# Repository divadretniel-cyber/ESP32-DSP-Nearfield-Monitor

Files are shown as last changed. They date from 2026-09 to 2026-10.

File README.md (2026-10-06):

# Nearfield Monitor with ESP32-DSP-4x50W-Amplifier

A studio monitor with a DSP amplifier board, based on an esp32-S3.

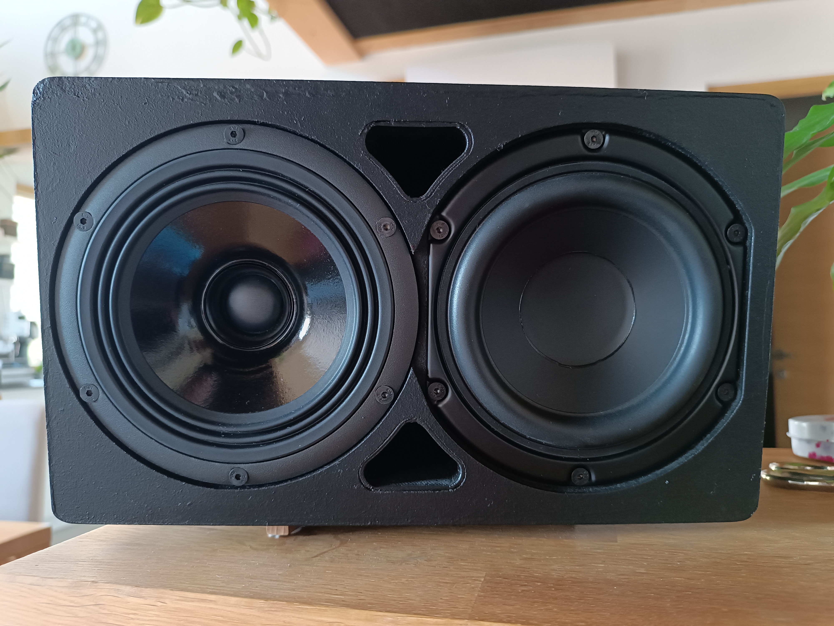
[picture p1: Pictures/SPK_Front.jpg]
PCB


# Capabilities

A compact 302 x 218 x 184 mm speaker with linear frequency response and wide frequency range.
Frequency response linear __+-1.5dB down to 35Hz__ after dsp correction.
  
A 2 channel ADC converts the incoming Differential signals to an I2S stream, the ESP32S3 then acts as DSP and splits the I2S stream to 2 Amplifier chips with digital input,
so they have the DAC integrated.

There are 2 different versions of the firmware. 
* Version 1 WIFI - Control: control the parameters via wifi. The esp32 generates a wifi access point, after connecting to it it opens your browser where you can set the DSP parameters.
* Version 2 USB - Control: control the parameters over usb. Just connect the board to a pc, open a browser like chrome, and open the html, there is a connect button where you can select the board. When using this version, no antenna is needed.
For a simple control an encoder can be connected, and a WS2812 led shows the wifi state and volume. Also a i2c display can be connected, but at the moment it has no firmware support.

# Parts used

Speakers used:
* LF Drivers: Peerless SDS-135F25CP02-04
  https://loudspeakerdatabase.com/Peerless/SDS-135F25CP02-04
* Coaxial Drivers: SICA 5,5 C 1,5 CP
  https://loudspeakerdatabase.com/SICA/5,5C1,5CP

Electronics:
* 120W Gan power supply set to 24V - https://ko.aliexpress.com/item/1005011912930487.html
* ADC: TLV320ADC6120 - A high performance ADC with a snr of 123dB, and THD+N of -95dB and it can be controlled over i2c
  https://www.ti.com/lit/ds/symlink/tlv320adc6120.pdf?ts=1788514452765
* MCU: ESP32-S3-WROOM-1U-N16R8 - ESP32S3 module with antenna connector, so an external antenna can be used for better wifi range. But the board features also a cutout, so a WROOM module with integrated antenna can be used too.
  https://documentation.espressif.com/esp32-s3-wroom-1_wroom-1u_datasheet_en.pdf
* AMP: 2x TAS5827 - Integrated I2S in Class D amplifier with 2x50W output. Also controllable via i2c. 
  https://www.ti.com/lit/ds/symlink/tas5827.pdf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

# Usage
The UI lets you route the 2 inputs to the 4 outputs like you want.
Next part is the global EQ, that means it will be applied to all outputs.
Ideal for applying correction EQ for a Speaker system.
The UI also features an auto EQ function, where a REW file can be pasted and automatic filters are applied. 
Then individial filters can be applied to each of the 4 outputs, or their phase can be flipped.
At the end the main volume can be set.
Its not necessary to use this firmware, you can design your own.

As you may recognize the firmware and gui html was written with claude code.

the html with the ui: https://github.com/divadretniel-cyber/ESP32-DSP-Nearfield-Monitor/blob/main/WEB-UI/index.html

Drawing of the Speaker, the br ports and the volume for the coax speaker are 3D printed.

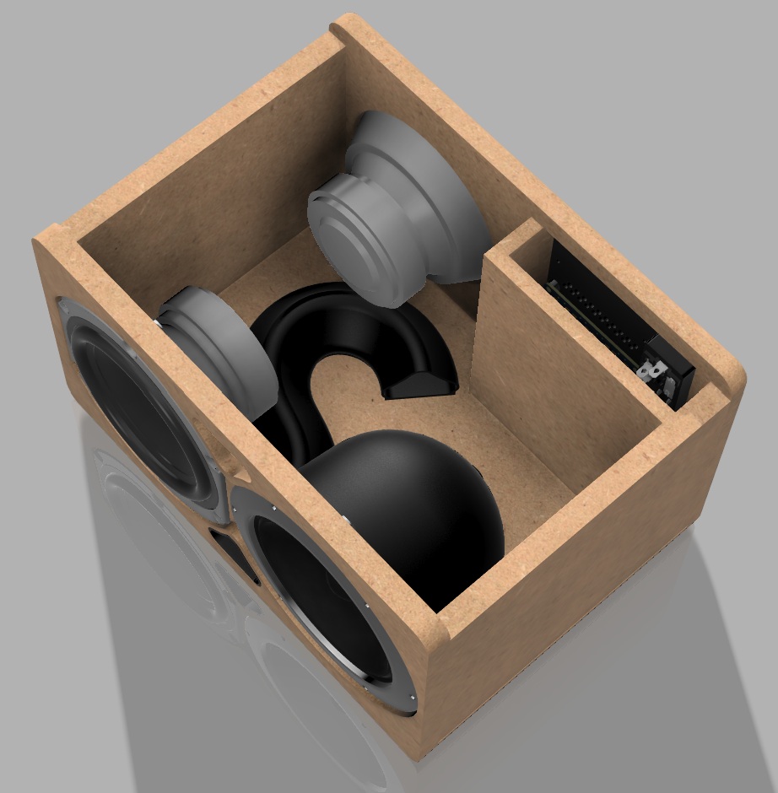
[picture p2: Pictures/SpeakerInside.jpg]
.

Measurement after calibration:

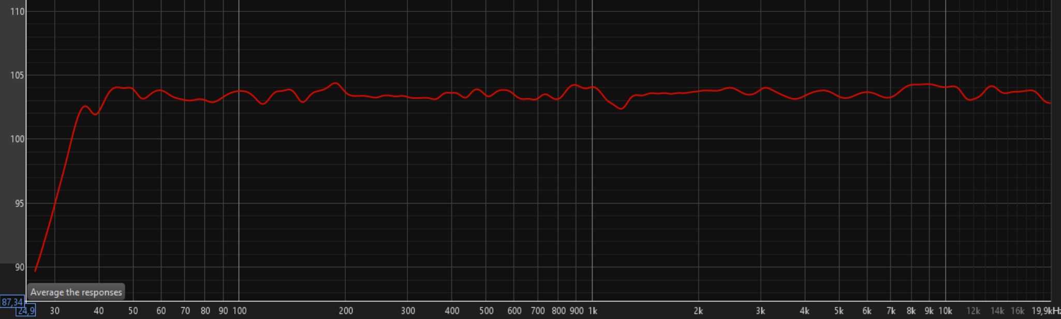
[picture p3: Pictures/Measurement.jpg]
Measurement in REW


Construction was done in 14mm Mdf and printed parts.
The amplifier board is mounted on a 2mm aluminum plate, with a heat conductive pad between the board and the plate.
The drawing is in this repo and also the stl files for printing.

Aluminum plate with mounted parts:

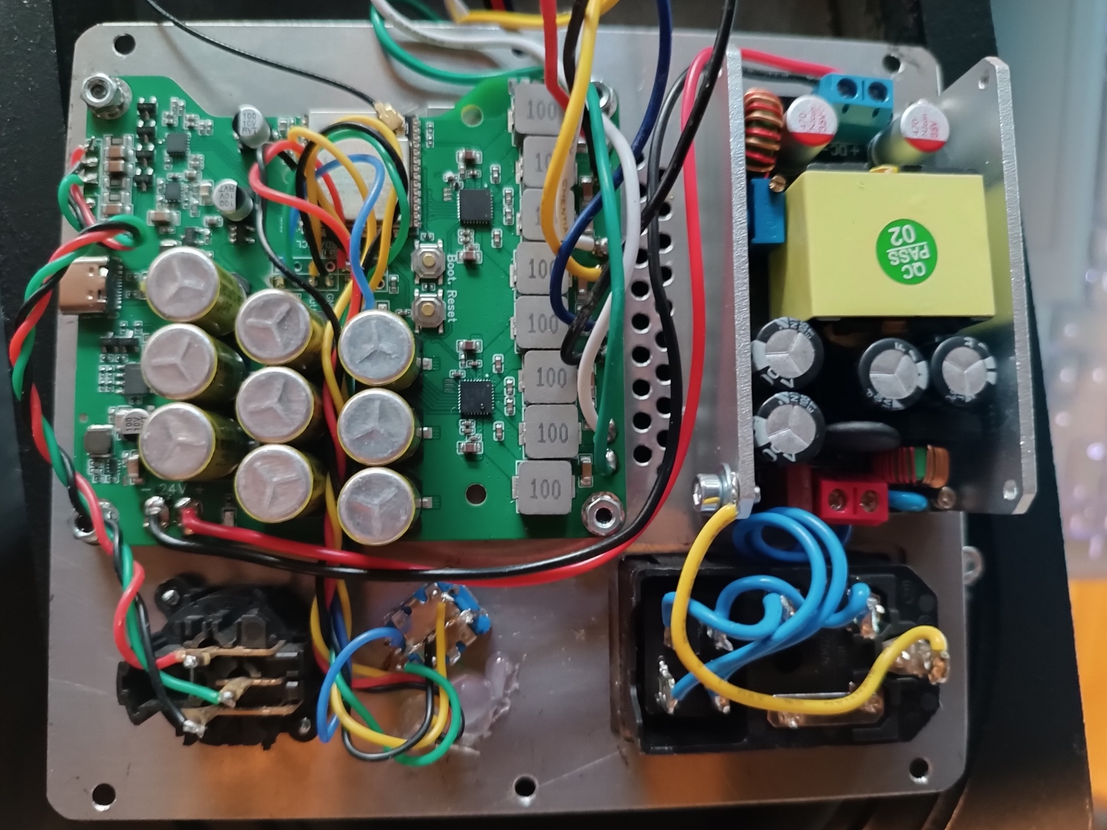
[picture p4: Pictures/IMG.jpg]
Plate with board and amp


New UI:

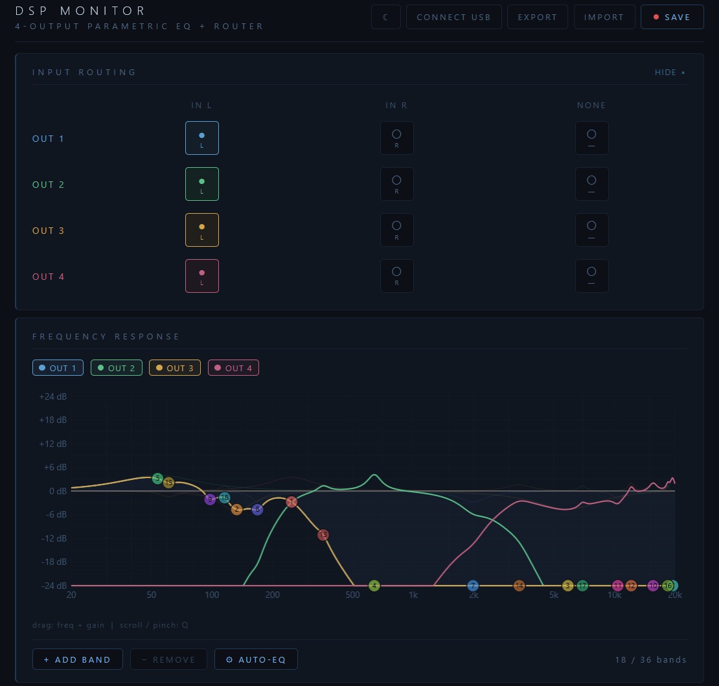
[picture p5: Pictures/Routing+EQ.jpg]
Routing + Global EQ

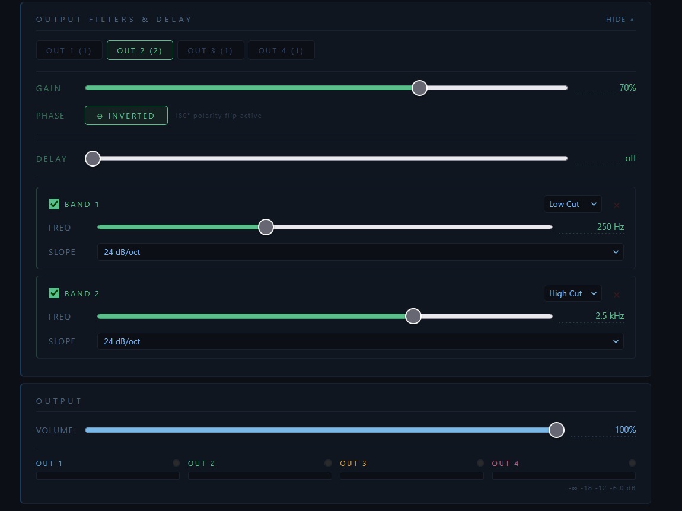
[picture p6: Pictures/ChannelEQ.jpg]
Per channel filter

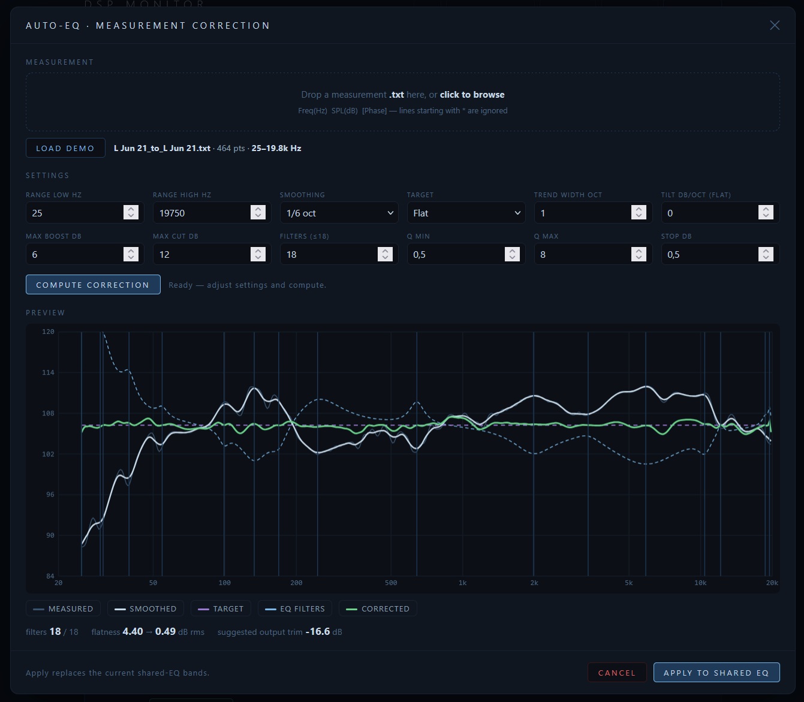
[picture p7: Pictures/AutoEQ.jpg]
Auto EQ


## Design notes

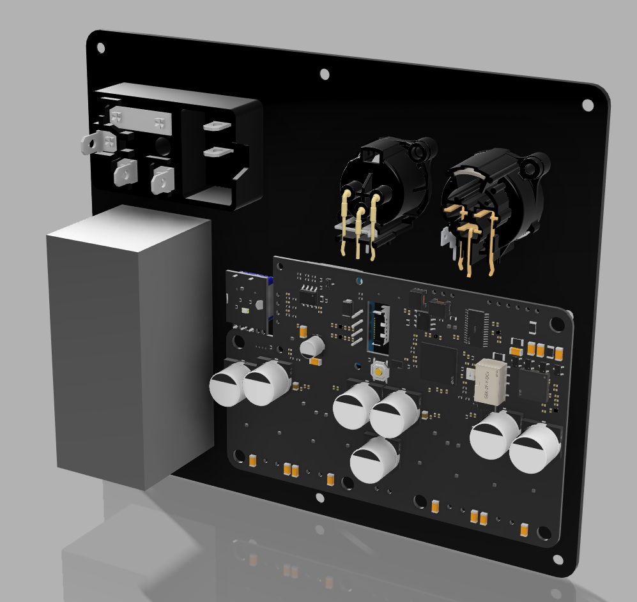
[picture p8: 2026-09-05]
Pictures/Plate Back.jpg

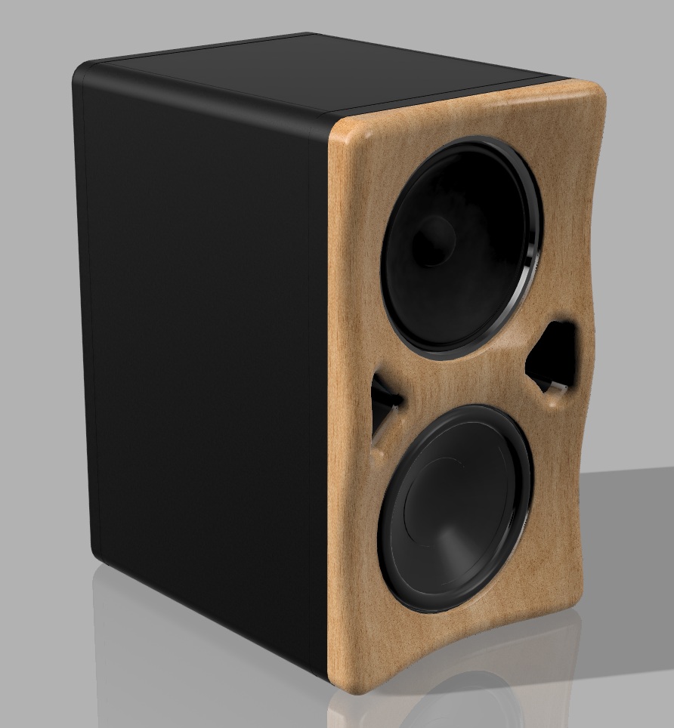
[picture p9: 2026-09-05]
Pictures/SpeakerFull.jpg

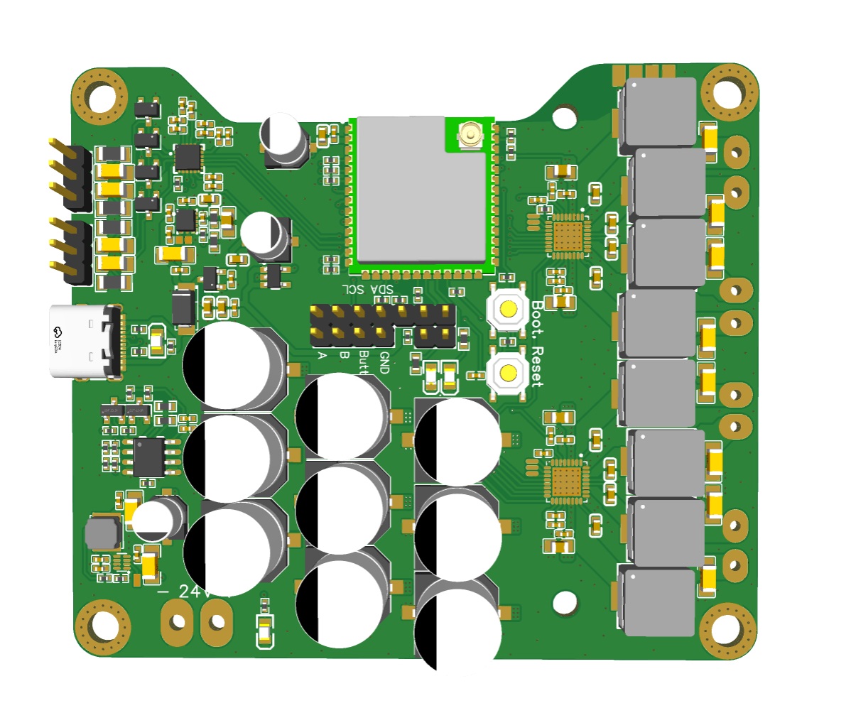
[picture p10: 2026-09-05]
Pictures/PCB_ESP.jpg

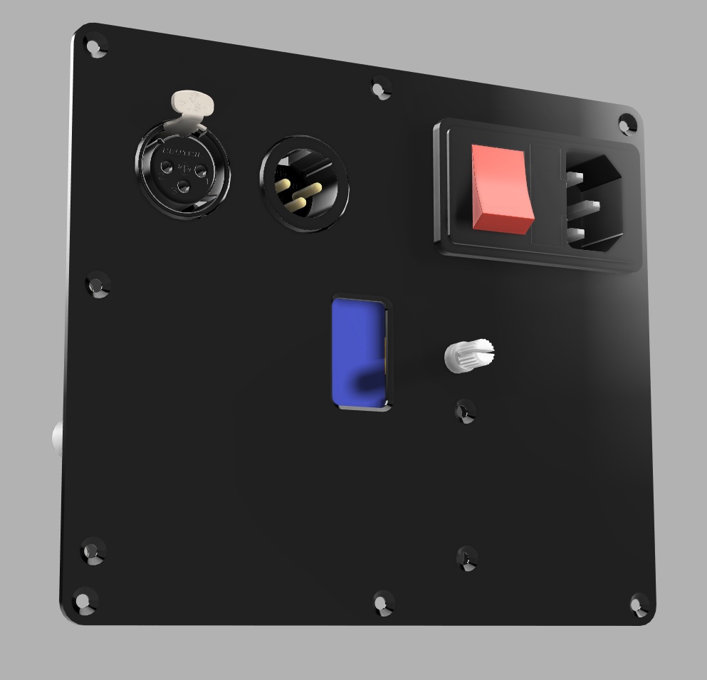
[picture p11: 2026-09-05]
Pictures/Plate Front.jpg

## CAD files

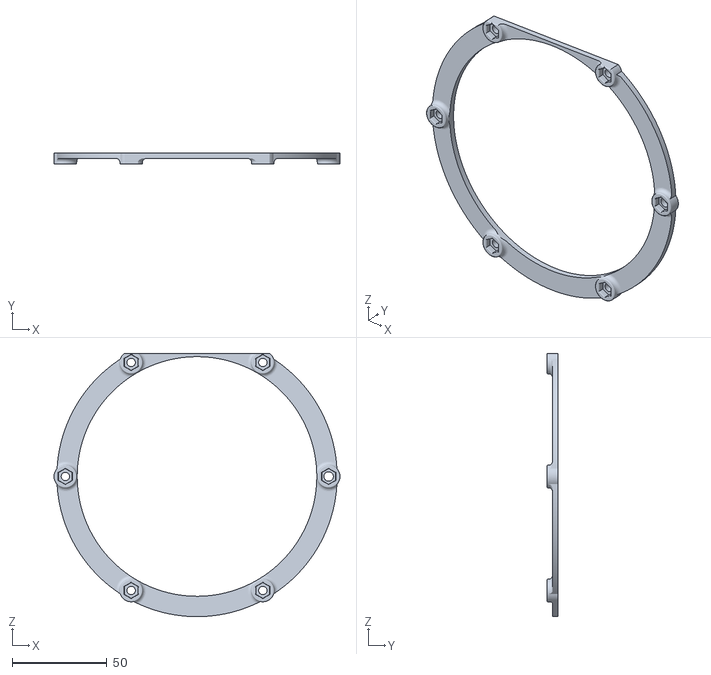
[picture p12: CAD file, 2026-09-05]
3D_Files/MidVolumeMountRing.stl
151.0 x 6.00 x 139.0

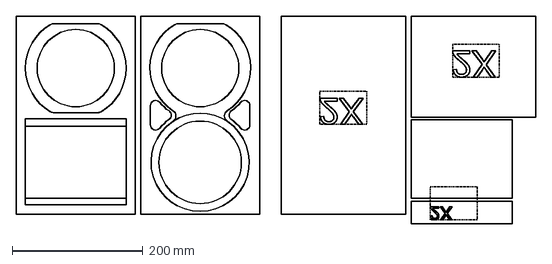
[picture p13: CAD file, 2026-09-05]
Drawing/Drawing.dxf
793.5 x 316.6 mm

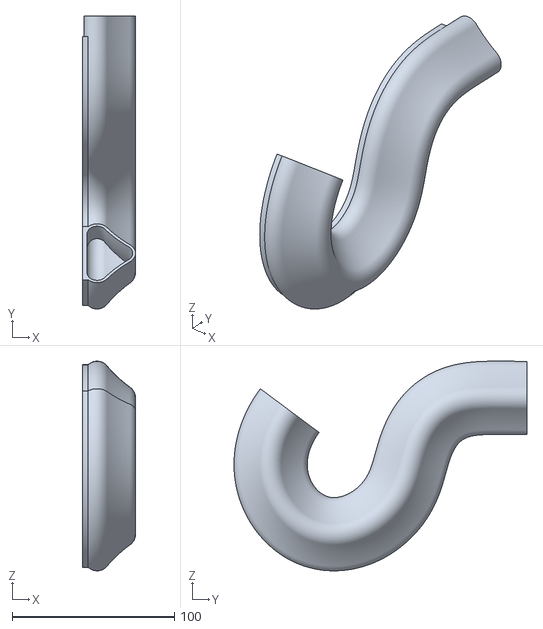
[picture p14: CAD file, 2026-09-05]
3D_Files/BrTube.stl
32.7 x 180.5 x 129.2

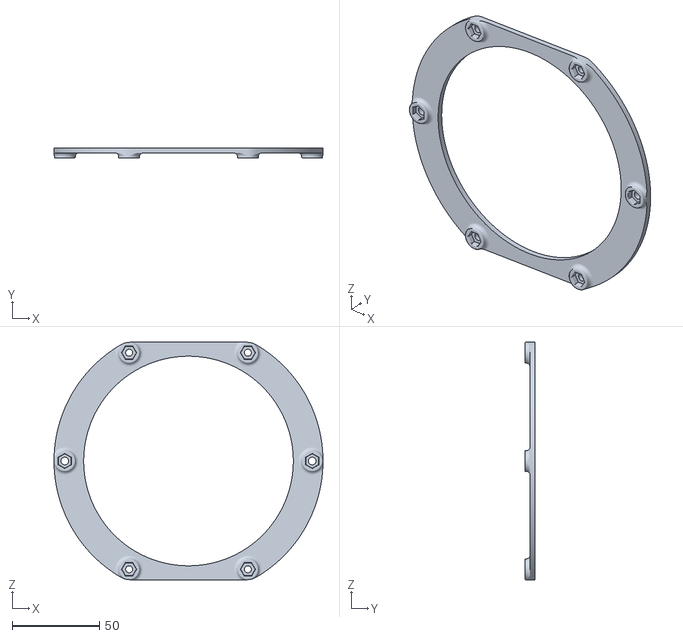
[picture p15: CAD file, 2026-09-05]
3D_Files/SubMountRing.stl
154.0 x 6.00 x 136.0

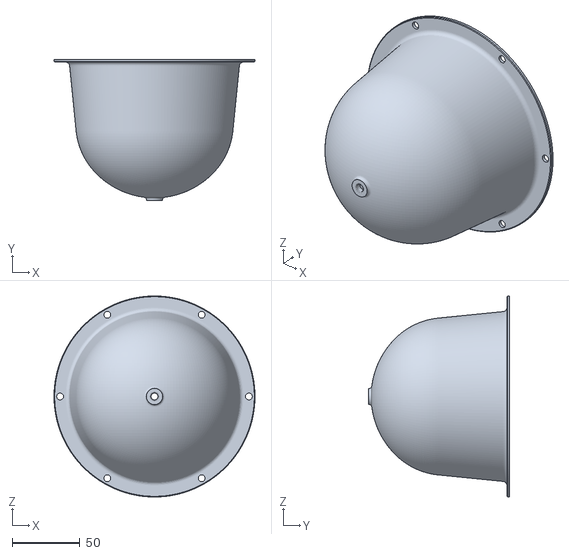
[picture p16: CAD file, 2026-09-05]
3D_Files/MidVolume.stl
148.0 x 104.0 x 148.0

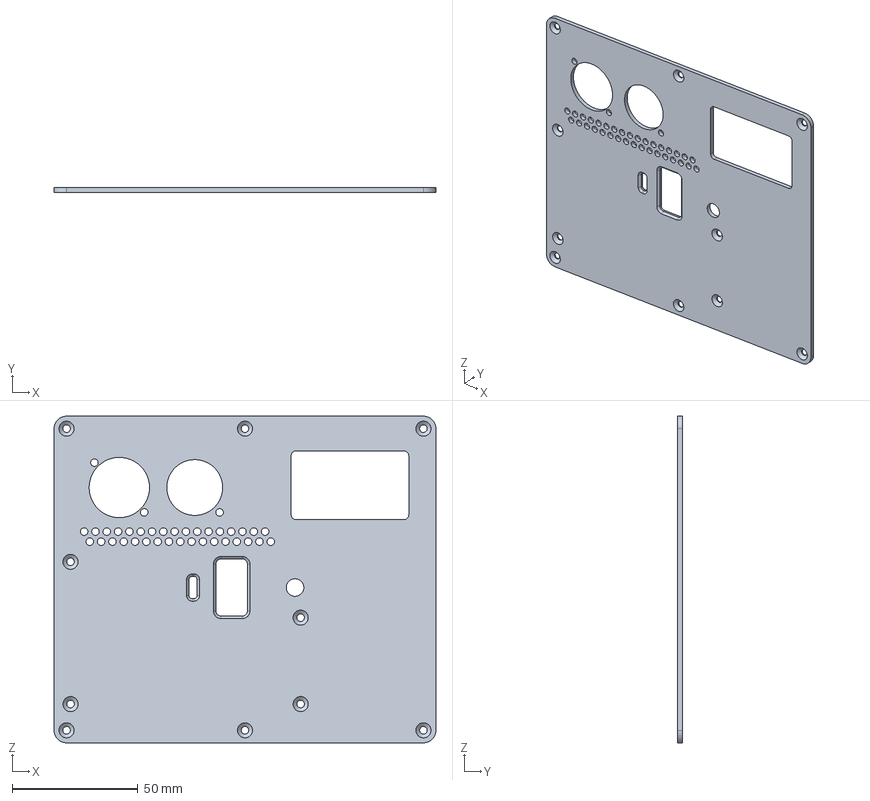
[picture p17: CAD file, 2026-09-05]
3D_Files/Amp Plate.step
152.0 x 2.00 x 130.0 mm

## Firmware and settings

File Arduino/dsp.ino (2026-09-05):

/*
 * audio_dsp.ino — ESP32-S3 + TLV320ADC6120 + 2x TAS5827
 *                 (dual standard-I2S, 4-channel DSP)
 * ==========================================================================
 *
 *  Signal chain (per audio frame, 48 kHz fixed):
 *    TLV320ADC6120  (standard stereo I2S, 32-bit, 24-in-32)
 *      -> 18-band shared parametric EQ (both channels)
 *      -> Routing: each of 4 outputs picks IN L, IN R, or silence
 *      -> Per-output gain (0..1)
 *      -> Per-output 8-band PEQ
 *      -> Per-output delay (0..25 ms @ 48 kHz = 0..1200 samples)
 *      -> Per-output phase invert
 *      -> Two standard stereo I2S streams:
 *           I2S0 TX (master) -> AMP1 SDIN = OUT 1 (L) + OUT 2 (R)
 *           I2S1 TX (slave)  -> AMP2 SDIN = OUT 3 (L) + OUT 4 (R)
 *
 *  Clocking (this is the change from the old TDM design):
 *    I2S0 is the I2S master and drives the shared BCLK + WS. The ADC (RX) and
 *    AMP1 (TX) live on I2S0. I2S1 is a TX-only SLAVE that reads the same
 *    BCLK/WS pins as inputs and clocks AMP2 — so both amps stay sample-locked.
 *    Standard stereo framing (the WS level identifies the channel) has no TDM
 *    slot-phase to latch wrong, which is what removes the boot-to-boot
 *    misalignment we had on the 4-slot TDM bus.
 *
 *  Hardware (ESP32-S3 Arduino core 3.x, IDF 5.x underneath):
 *    I2C:          SDA=GPIO8  SCL=GPIO9  @ 400 kHz
 *      ADC  TLV320ADC6120  = 0x4E
 *      AMP1 TAS5827        = 0x61
 *      AMP2 TAS5827        = 0x60
 *    I2S0 (master, full-duplex, standard stereo, 32-bit):
 *      BCLK   = GPIO4   (shared, driven by I2S0)
 *      WS     = GPIO5   (shared, driven by I2S0)
 *      DOUT   = GPIO6   -> AMP1 SDIN
 *      DIN    = GPIO7   <- ADC SDOUT
 *    I2S1 (slave, TX only, standard stereo, 32-bit):
 *      BCLK/WS = GPIO4/GPIO5 (shared, read as inputs)
 *      DOUT    = GPIO21 -> AMP2 SDIN
 *    AMP shared PDN: GPIO10 (board-inverted: LOW=on, HIGH=off)
 *
 *  Controls:
 *    Rotary encoder: A=GPIO15  B=GPIO16
 *    Button:         GPIO17 (active-low, internal pull-up)
 *      Press -> toggle volume-adjust mode
 *
 *  Status LED (WS2812 on GPIO12):
 *    Volume mode OFF:
 *      Green  = ready
 *      Red    = error (5 s flash / fatal latch)
 *    Volume mode ON:
 *      Gradient green (0%) -> yellow (50%) -> red (100%)
 *      Flashing red at 100%
 *
 *  Filter types (matches old UI):
 *    0=Peak  1=LowShelf  2=HighShelf  3=HighCut(LPF)
 *    4=LowCut(HPF)  5=Notch  6=Bypass
 *  HPF/LPF steepness:
 *    6=1st-order  12=2nd-order BW  24=LR4  48=LR8
 *
 *  Configuration: over USB serial (WebSerial UI) -> serviceSerialConsole()
 *
 *  Libraries:
 *    ArduinoJson  Preferences
 *    IDF drivers: i2c_master, i2s_std  (used directly from Arduino core 3.x)
 *
 *  Board: ESP32S3 Dev Module, USB CDC On Boot: Enabled
 */

#include <Arduino.h>
#include <math.h>

#include <Preferences.h>
#include <ArduinoJson.h>
#include <nvs_flash.h>
#include <Adafruit_NeoPixel.h>

#include "freertos/FreeRTOS.h"
#include "freertos/task.h"
#include "freertos/semphr.h"
#include "driver/gpio.h"
#include "driver/i2c_master.h"
#include "driver/i2s_std.h"
#include "esp_heap_caps.h"
#include "esp_rom_gpio.h"
#include "soc/gpio_sig_map.h"

/* ==================================================================
 *  Pins
 * ================================================================== */
#define PIN_LED_RED          13
#define PIN_LED_GREEN        14

#define PIN_STATUS_LED       12        /* WS2812 data line */
#define PIN_BUTTON           17        /* GPIO17 — press toggles volume-adjust mode */

/* Rotary encoder */
#define PIN_ENC_A            15        /* Encoder channel A */
#define PIN_ENC_B            16        /* Encoder channel B */

#define PIN_I2C_SDA          GPIO_NUM_8
#define PIN_I2C_SCL          GPIO_NUM_9

#define PIN_I2S_BCLK         GPIO_NUM_4
#define PIN_I2S_FSYNC        GPIO_NUM_5     /* WS / LRCLK */
#define PIN_I2S_DOUT         GPIO_NUM_6     /* I2S0 TX -> AMP1 */
#define PIN_I2S_DOUT2        GPIO_NUM_21    /* I2S1 TX -> AMP2 (was the GPIO-matrix mirror) */
#define PIN_I2S_DIN          GPIO_NUM_7     /* I2S0 RX <- ADC */

#define PIN_AMP_PDN          GPIO_NUM_10
#define AMP_PDN_ON           0
#define AMP_PDN_OFF          1

/* ==================================================================
 *  Audio format — standard stereo I2S, 32-bit slots, 24-in-32 data
 * ================================================================== */
#define SAMPLE_RATE_HZ      48000
#define STD_SLOTS           2          /* L + R per frame */
#define BUFFER_FRAMES       16         /* small block -> low I/O latency; raise if dropouts */
#define PCM_SHIFT           8          /* 24-bit sample sits in the top 24 of 32 */

/* ==================================================================
 *  I2C addresses
 * ================================================================== */
#define ADC_I2C_ADDR     0x4E
#define AMP1_I2C_ADDR    0x61
#define AMP2_I2C_ADDR    0x60
#define I2C_FREQ_HZ      400000

/* ==================================================================
 *  TLV320ADC6120 registers (Page 0)
 * ================================================================== */
#define ADC_REG_PAGE_SEL      0x00
#define ADC_REG_SLEEP_CFG     0x02
#define ADC_REG_ASI_CFG0      0x07
#define ADC_REG_ASI_CFG1      0x08
#define ADC_REG_ASI_CFG2      0x09
#define ADC_REG_ASI_CH1       0x0B
#define ADC_REG_ASI_CH2       0x0C
#define ADC_REG_MST_CFG0      0x13
#define ADC_REG_DSP_CFG0      0x6B
#define ADC_REG_IN_CH_EN      0x73
#define ADC_REG_ASI_OUT_CH_EN 0x74
#define ADC_REG_PWR_CFG       0x75
#define ADC_REG_DEV_STS0      0x76

/* ==================================================================
 *  TAS5827 registers
 * ================================================================== */
#define TAS_REG_PAGE_SEL      0x00
#define TAS_REG_RESET         0x01
#define TAS_REG_DEVICE_CTRL1  0x02
#define TAS_REG_DEVICE_CTRL2  0x03
#define TAS_REG_SAP_CTRL1     0x33
#define TAS_REG_SAP_CTRL2     0x34
#define TAS_REG_SAP_CTRL3     0x35
#define TAS_REG_FS_MON        0x37
#define TAS_REG_BCK_MON       0x38
#define TAS_REG_CLKDET_STS    0x39
#define TAS_REG_DIG_VOL       0x4C
#define TAS_REG_AGAIN         0x54
#define TAS_REG_POWER_STATE   0x68
#define TAS_REG_CHAN_FAULT    0x70
#define TAS_REG_GLOBAL_FAULT1 0x71
#define TAS_REG_GLOBAL_FAULT2 0x72
#define TAS_REG_BOOK_SEL      0x7F

#define DCTRL2_MODE_HIZ       0x02
#define DCTRL2_MODE_PLAY      0x03

/* ==================================================================
 *  Persistent settings (NVS via Preferences)
 * ================================================================== */
static Preferences    prefs;

/* ==================================================================
 *  Status LED — single WS2812 on PIN_STATUS_LED
 * ================================================================== */
#define RGB(r, g, b)  ((uint32_t)(((uint8_t)(r) << 16) | \
                                  ((uint8_t)(g) << 8)  | \
                                   (uint8_t)(b)))

static const uint32_t STATUS_COLOR_ERROR    = RGB(255,   0,   0);
static const uint32_t STATUS_COLOR_READY    = RGB(  0, 255,  20);
static const uint32_t STATUS_COLOR_BLACK    = RGB(  0,   0,   0);

static const uint32_t ERROR_FLASH_MS        = 5000;

static Adafruit_NeoPixel statusLed(1, PIN_STATUS_LED, NEO_GRB + NEO_KHZ800);

static volatile uint32_t g_errorUntilMs = 0;
static volatile bool     g_errorFatal   = false;

static uint32_t          g_lastLedColorWritten = 0xFFFFFFFF;

/* ==================================================================
 *  Button + encoder state
 *
 *  Button (GPIO17, active-low, internal pull-up):
 *    Press (>= debounce) -> toggle volume-adjust mode
 *
 *  The button is sampled in loop() at ~10 ms intervals.
 *  Press detection:
 *    - Track when button first goes LOW (g_btnPressStartMs).
 *    - On release (LOW -> HIGH) decide short vs long by elapsed time.
 *    - Require button to return HIGH before next press registers.
 *
 *  Encoder (GPIO15=A, GPIO16=B):
 *    Read via interrupt on A. Direction determined by B state at A's
 *    falling edge (standard quadrature: B=LOW means CW/+, B=HIGH=CCW/-).
 *    A volatile step counter is accumulated; loop() drains it.
 * ================================================================== */

/* Button timing */
static const uint32_t BTN_LONG_PRESS_MS  = 3000;
static const uint32_t BTN_DEBOUNCE_MS    = 50;

static bool     g_btnWasLow        = false;   /* last sampled state */
static uint32_t g_btnPressStartMs  = 0;       /* millis() when button first went LOW */
static bool     g_btnArmed         = true;    /* false while held, reset on release */

/* Encoder — software quadrature debounce
 *
 *  A mechanical encoder bounces on both A and B contacts. A bare
 *  falling-edge ISR on A counts bounce spikes as real steps, so we
 *  use a full quadrature state machine instead:
 *
 *    State table (Gray code, reading A:B each ISR tick):
 *      00 -> 01 -> 11 -> 10 -> 00  =  clockwise (CW)
 *      00 -> 10 -> 11 -> 01 -> 00  =  counter-clockwise (CCW)
 *
 *  The ISR fires on ANY edge of A or B (CHANGE mode). At each
 *  transition we look up (prevState << 2 | curState) in a 16-entry
 *  table: +1 for a valid CW transition, -1 for CCW, 0 for invalid
 *  (bounce or missed step). We only accumulate the step counter when
 *  we complete a full detent cycle (4 valid transitions in the same
 *  direction), which rejects almost all mechanical bounce.
 *
 *  g_encSteps is written and read as a single aligned 32-bit word;
 *  on Xtensa that is atomic, so no mutex is needed between the ISR
 *  and loop(). */

/* Transition table: index = (prevAB << 2) | curAB, value = direction */
static const int8_t ENC_TABLE[16] DRAM_ATTR = {
/*       cur: 00  01  10  11          prev: */
/*  00 */     0, -1, +1,  0,
/*  01 */    +1,  0,  0, -1,
/*  10 */    -1,  0,  0, +1,
/*  11 */     0, +1, -1,  0,
};

static volatile int  g_encSteps    = 0;   /* +N = CW, -N = CCW; drained by loop() */
static volatile int8_t g_encState  = 0;   /* last AB reading (0..3) */
static volatile int  g_encAccum    = 0;   /* sub-detent accumulator */

/* Volume mode */
static bool     g_volumeMode       = false;   /* true while adjusting volume */
static uint32_t g_volumeModeExitMs = 0;       /* auto-exit after 5 s of no input */
static const uint32_t VOL_MODE_TIMEOUT_MS = 5000;

/* Volume step size: 5% of full scale (0..1) */
static const float VOL_STEP = 0.05f;

/* Flash state for 100% volume indicator */
static uint32_t g_volFlashNextMs   = 0;
static bool     g_volFlashOn       = true;
static const uint32_t VOL_FLASH_PERIOD_MS = 250;

/* ==================================================================
 *  IDF driver handles
 * ================================================================== */
static i2c_master_bus_handle_t s_i2c_bus  = NULL;
static i2c_master_dev_handle_t s_adc_dev  = NULL;
static i2c_master_dev_handle_t s_amp1_dev = NULL;
static i2c_master_dev_handle_t s_amp2_dev = NULL;

static i2s_chan_handle_t s_tx0_handle = NULL;   /* I2S0 TX -> AMP1 (OUT1/2) */
static i2s_chan_handle_t s_rx_handle  = NULL;   /* I2S0 RX <- ADC           */
static i2s_chan_handle_t s_tx1_handle = NULL;   /* I2S1 TX -> AMP2 (OUT3/4) */

/* ==================================================================
 *  DSP state
 * ================================================================== */
static SemaphoreHandle_t dspMutex = NULL;

volatile float volume = 1.0f;
/* Cached perceptual taper g_volGain = volume^2.5, recomputed only when the
 * volume changes, so the audio task never calls powf() (a flash function)
 * in its per-buffer path. */
volatile float g_volGain = 1.0f;

volatile float outputGain[4]  = {1.0f, 1.0f, 1.0f, 1.0f};
volatile bool  outputPhase[4] = {false, false, false, false};
volatile int   routing[4]     = {0, 1, 0, 1};

#define FTYPE_PEAK       0
#define FTYPE_LOW_SHELF  1
#define FTYPE_HIGH_SHELF 2
#define FTYPE_HIGH_CUT   3
#define FTYPE_LOW_CUT    4
#define FTYPE_NOTCH      5
#define FTYPE_BYPASS     6

struct Biquad {
    float b0, b1, b2, a1, a2;
    float s1, s2;
};

static inline void resetBiquad(Biquad &b) { b.s1 = b.s2 = 0.0f; }

static inline float IRAM_ATTR processBiquad(Biquad &b, float x) {
    float y  = b.b0 * x + b.s1;
    b.s1     = b.b1 * x - b.a1 * y + b.s2;
    b.s2     = b.b2 * x - b.a2 * y;
    return y;
}

#define NUM_EQ_BANDS 36

struct EQBand {
    volatile float freq;
    volatile float gain;
    volatile float q;
    volatile int   type;
    volatile int   steepness;
    volatile bool  active;
};

EQBand sharedEQ[NUM_EQ_BANDS];

static void initSharedEQ() {
    for (int i = 0; i < NUM_EQ_BANDS; i++) {
        sharedEQ[i] = {1000.0f, 0.0f, 0.7f, FTYPE_BYPASS, 12, false};
    }
}

#define NUM_OUTPUTS   4
#define MAX_OUT_BANDS 8

struct OutBand {
    volatile float freq;
    volatile float gain;
    volatile float q;
    volatile int   type;
    volatile int   steepness;
    volatile bool  active;
    volatile bool  on;
};

OutBand     outBands[NUM_OUTPUTS][MAX_OUT_BANDS];
volatile int outBandCount[NUM_OUTPUTS] = {0};

static void initOutBands() {
    for (int o = 0; o < NUM_OUTPUTS; o++) {
        outBandCount[o] = 0;
        for (int i = 0; i < MAX_OUT_BANDS; i++) {
            outBands[o][i] = {1000.0f, 0.0f, 0.7f, FTYPE_BYPASS, 12, false, false};
        }
    }
}

#define DELAY_MAX_MS    25.0f
#define DELAY_MAX_SAMP  1201

volatile int delayInSamples[NUM_OUTPUTS] = {0};
float        delayBuf[NUM_OUTPUTS][DELAY_MAX_SAMP];
int          delayHead[NUM_OUTPUTS] = {0};

static void initDelayBuffers() {
    for (int o = 0; o < NUM_OUTPUTS; o++) {
        delayInSamples[o] = 0;
        delayHead[o]      = 0;
        memset(delayBuf[o], 0, sizeof(delayBuf[o]));
    }
}

static inline float IRAM_ATTR processDelay(int o, float x) {
    int d = delayInSamples[o];
    if (d == 0) return x;
    delayBuf[o][delayHead[o]] = x;
    if (++delayHead[o] >= DELAY_MAX_SAMP) delayHead[o] = 0;
    int ri = delayHead[o] - d;
    if (ri < 0) ri += DELAY_MAX_SAMP;
    return delayBuf[o][ri];
}

DRAM_ATTR Biquad bqSharedL[NUM_EQ_BANDS][4];
DRAM_ATTR Biquad bqSharedR[NUM_EQ_BANDS][4];
DRAM_ATTR Biquad bqOut[NUM_OUTPUTS][MAX_OUT_BANDS][4];
DRAM_ATTR int    sharedEQStages[NUM_EQ_BANDS];
DRAM_ATTR int    outBandStages[NUM_OUTPUTS][MAX_OUT_BANDS];

DRAM_ATTR int activeSharedBands[NUM_EQ_BANDS];
DRAM_ATTR int activeSharedCount = 0;
DRAM_ATTR int activeOutBands[NUM_OUTPUTS][MAX_OUT_BANDS];
DRAM_ATTR int activeOutCount[NUM_OUTPUTS] = {0};

/* ==================================================================
 *  Level meter state
 * ================================================================== */
#define METER_DECAY        0.92f
#define METER_CLIP_THRESH  1.0f
#define METER_CLIP_HOLD_MS 1000

DRAM_ATTR static volatile float    g_meterPeak[NUM_OUTPUTS]        = {0};
DRAM_ATTR static volatile uint32_t g_meterClipUntilMs[NUM_OUTPUTS] = {0};

/* ==================================================================
 *  Click-suppression fade state
 * ================================================================== */
#define FADE_SAMPLES   240

enum FadeState : uint8_t {
    FADE_NONE = 0,
    FADE_DOWN,
    FADE_UP,
};

DRAM_ATTR static volatile uint32_t g_fadeRequest = 0;
DRAM_ATTR static uint32_t          g_fadeSeen    = 0;
DRAM_ATTR static FadeState         g_fadeState   = FADE_NONE;
DRAM_ATTR static int               g_fadePos     = 0;
DRAM_ATTR static float             g_fadeLastEnv  = 1.0f;
DRAM_ATTR static float             g_fadeStartEnv = 1.0f;

DRAM_ATTR static float g_lastOutSample[NUM_OUTPUTS] = {0, 0, 0, 0};

static inline void resetSignalPathState() {
    for (int i = 0; i < NUM_EQ_BANDS; i++) {
        for (int k = 0; k < 4; k++) {
            resetBiquad(bqSharedL[i][k]);
            resetBiquad(bqSharedR[i][k]);
        }
    }
    for (int o = 0; o < NUM_OUTPUTS; o++) {
        for (int i = 0; i < MAX_OUT_BANDS; i++) {
            for (int k = 0; k < 4; k++) resetBiquad(bqOut[o][i][k]);
        }
        memset(delayBuf[o], 0, sizeof(delayBuf[o]));
        delayHead[o] = 0;
    }
}

static inline void requestFade() {
    g_fadeRequest++;
}

/* ==================================================================
 *  Coefficient computation
 * ================================================================== */
static inline double wn(float freq) {
    return 2.0 * M_PI * (double)freq / (double)SAMPLE_RATE_HZ;
}

static void coeffPeak(Biquad &b, float freq, float gainDb, float q) {
    double A = pow(10.0, (double)gainDb / 40.0), w = wn(freq);
    double cw = cos(w), alpha = sin(w) / (2.0 * q);
    double b0 = 1 + alpha * A, b1 = -2 * cw, b2 = 1 - alpha * A;
    double a0 = 1 + alpha / A;
    b.b0 = (float)(b0 / a0); b.b1 = (float)(b1 / a0); b.b2 = (float)(b2 / a0);
    b.a1 = (float)(-2 * cw / a0); b.a2 = (float)((1 - alpha / A) / a0);
}

static void coeffLowShelf(Biquad &b, float freq, float gainDb, float q) {
    double A = pow(10.0, (double)gainDb / 40.0), w = wn(freq);
    double cw = cos(w), sw = sin(w), a = sw / (2.0 * q), sA = sqrt(A);
    double b0 = A * ((A + 1) - (A - 1) * cw + 2 * sA * a);
    double b1 = 2 * A * ((A - 1) - (A + 1) * cw);
    double b2 = A * ((A + 1) - (A - 1) * cw - 2 * sA * a);
    double a0 = (A + 1) + (A - 1) * cw + 2 * sA * a;
    double a1 = -2 * ((A - 1) + (A + 1) * cw);
    double a2 = (A + 1) + (A - 1) * cw - 2 * sA * a;
    b.b0 = (float)(b0 / a0); b.b1 = (float)(b1 / a0); b.b2 = (float)(b2 / a0);
    b.a1 = (float)(a1 / a0); b.a2 = (float)(a2 / a0);
}

static void coeffHighShelf(Biquad &b, float freq, float gainDb, float q) {
    double A = pow(10.0, (double)gainDb / 40.0), w = wn(freq);
    double cw = cos(w), sw = sin(w), a = sw / (2.0 * q), sA = sqrt(A);
    double b0 = A * ((A + 1) + (A - 1) * cw + 2 * sA * a);
    double b1 = -2 * A * ((A - 1) + (A + 1) * cw);
    double b2 = A * ((A + 1) + (A - 1) * cw - 2 * sA * a);
    double a0 = (A + 1) - (A - 1) * cw + 2 * sA * a;
    double a1 = 2 * ((A - 1) - (A + 1) * cw);
    double a2 = (A + 1) - (A - 1) * cw - 2 * sA * a;
    b.b0 = (float)(b0 / a0); b.b1 = (float)(b1 / a0); b.b2 = (float)(b2 / a0);
    b.a1 = (float)(a1 / a0); b.a2 = (float)(a2 / a0);
}

static void coeffNotch(Biquad &b, float freq, float q) {
    double w = wn(freq), cw = cos(w), a = sin(w) / (2.0 * q), a0 = 1 + a;
    b.b0 = (float)(1 / a0); b.b1 = (float)(-2 * cw / a0); b.b2 = (float)(1 / a0);
    b.a1 = (float)(-2 * cw / a0); b.a2 = (float)((1 - a) / a0);
}

static void coeffBypass(Biquad &b) {
    b.b0 = 1; b.b1 = 0; b.b2 = 0; b.a1 = 0; b.a2 = 0;
}

static void coeff1stLPF(Biquad &b, float freq) {
    double K = tan(M_PI * (double)freq / (double)SAMPLE_RATE_HZ);
    double n = 1.0 / (1.0 + K);
    b.b0 = (float)(K * n); b.b1 = (float)(K * n); b.b2 = 0;
    b.a1 = (float)((K - 1) / (K + 1)); b.a2 = 0;
}
static void coeff1stHPF(Biquad &b, float freq) {
    double K = tan(M_PI * (double)freq / (double)SAMPLE_RATE_HZ);
    double n = 1.0 / (1.0 + K);
    b.b0 = (float)(n); b.b1 = (float)(-n); b.b2 = 0;
    b.a1 = (float)((K - 1) / (K + 1)); b.a2 = 0;
}
/* 2nd-order LPF/HPF with explicit Q. The plain coeff2ndLPF/HPF wrappers
 * use Butterworth Q (0.7071). Higher-order Linkwitz-Riley cascades use the
 * Butterworth Q-pairs below. */
static void coeff2ndLPF_Q(Biquad &b, float freq, double Q) {
    double w = wn(freq), cw = cos(w), a = sin(w) / (2.0 * Q), a0 = 1 + a;
    b.b0 = (float)((1 - cw) / (2 * a0));
    b.b1 = (float)((1 - cw) / a0);
    b.b2 = (float)((1 - cw) / (2 * a0));
    b.a1 = (float)(-2 * cw / a0); b.a2 = (float)((1 - a) / a0);
}
static void coeff2ndHPF_Q(Biquad &b, float freq, double Q) {
    double w = wn(freq), cw = cos(w), a = sin(w) / (2.0 * Q), a0 = 1 + a;
    b.b0 = (float)((1 + cw) / (2 * a0));
    b.b1 = (float)(-(1 + cw) / a0);
    b.b2 = (float)((1 + cw) / (2 * a0));
    b.a1 = (float)(-2 * cw / a0); b.a2 = (float)((1 - a) / a0);
}
static inline void coeff2ndLPF(Biquad &b, float freq) { coeff2ndLPF_Q(b, freq, 0.70710678); }
static inline void coeff2ndHPF(Biquad &b, float freq) { coeff2ndHPF_Q(b, freq, 0.70710678); }

/* Butterworth section Q values, used to build Linkwitz-Riley filters as a
 * cascade of two equal-order Butterworth filters:
 *   LR4 (24 dB/oct) = two 2nd-order Butterworth (Q = 0.7071 each)
 *   LR8 (48 dB/oct) = two 4th-order Butterworth; each 4th-order Butterworth
 *                     is a 0.5412 + 1.3066 Q pair, so LR8 = these four Qs. */
static const double LR8_Q[4] = { 0.54119610, 1.30656296, 0.54119610, 1.30656296 };
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
void loop() {
    serviceSerialConsole();

    serviceDeferredSave();
    serviceControls();
    statusLedRefresh();
    amp_fault_service();

    vTaskDelay(pdMS_TO_TICKS(10));
}
